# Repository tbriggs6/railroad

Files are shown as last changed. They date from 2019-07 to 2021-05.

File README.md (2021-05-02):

# railroad

Railroad Signal Controller

The Shippensburg Railroad Museum was restoring an antique railroad signalling lantern for the museum.  They asked me if I could help them activate the signals to follow the original standard patterns (e.g. go, stop, proceed with caution).  I agreed, and designed this board and the attached code for the embedded micrcontroller.

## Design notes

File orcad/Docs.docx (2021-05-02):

# Railroad Controller Board

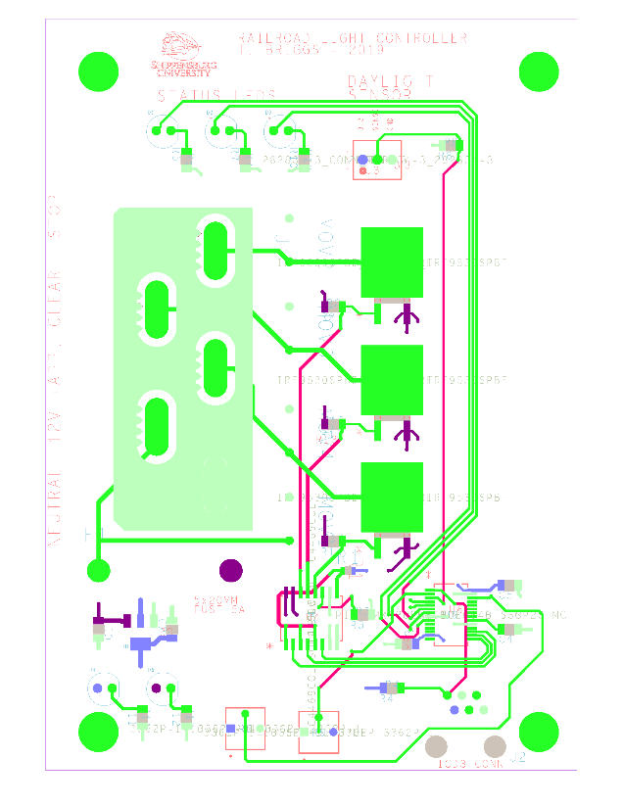
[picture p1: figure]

12V Fuse – 20mm x 5mm – 5A
Slow Blow (60 watt)

Daylight Sensor

Red (3V3+)

Yellow (Sensor)

Black (3V3-, Ground)

Adjust Light Speed

CCW – Faster

CW – Slower

Max CCW – Stop

Min CCW – 10 seconds

Adjust Daylight Cutoff

CCW – Darker

CW – Lighter

Full CCW – Always Off

Full CW – Always On

Status LEDs – Follow external lights

Stop Clear Approach

f

3mm Mounting Holes

Wires to the lights:

STOP

CLEAR

APPROACH

12VDC +

Ground / 12VDC -

# Theory of Operation

- Supports operation of three output channels corresponding to:
  - STOP,
  - CLEAR,
  - APPROACH.
- Only one output channel will be energized at a time.
- Output channel is connected to the positive rail of the external 12 VDC power supply
- Each output channel is expected to share a common ground with the negative rail of the 12 VDC supply.
- The speed of the pattern is controlled with a trimmer pot – allows speed from a fraction of second through approximately 30 seconds per channel, or 90 seconds for a complete cycle
- A daylight sensor is used to detect when there is sufficient sunlight for proper operation
- A trimmer pot can be used to adjust the level of sunlight that is sufficient
- Turning the daylight trimmer to one extreme will disable the output operation of the controller
- Turning the daylight trimmer to the other extreme will always enable the output operation of the controller (i.e. ignore the daylight sensor)
- The yellow power LED (bottom left corner of diagram) shows a sufficient 3.3V rail
- The red power LED (also bottom left corner) shows a sufficient 12V rail
- If the input fuse is blown then neither of the power LEDs will be lit
- The three status LEDs light-up with the corresponding output channel:
  - GREEN – Approach
  - YELLOW – Clear
  - RED - Stop

# Installation Notes

- The large 5-posn screw-down block holds the “high” voltage (12VDC connection)
  - Connect approximately 12 – 17 VDC to the indicated terminals
  - Connect the high-side of the signal LEDs to the output channels
- The small 3-posn screw-down block holds the “low” voltage daylight sensor
- The mounting holes are 3in and 4.5in (see template on page 1) and accommodate #4 - #8 machine screws.
- Negative rail should be connected to chassis ground or (preferably) earth ground to protect battery and other components from lightening, ground bounce, and attenuation due to length of buried wire

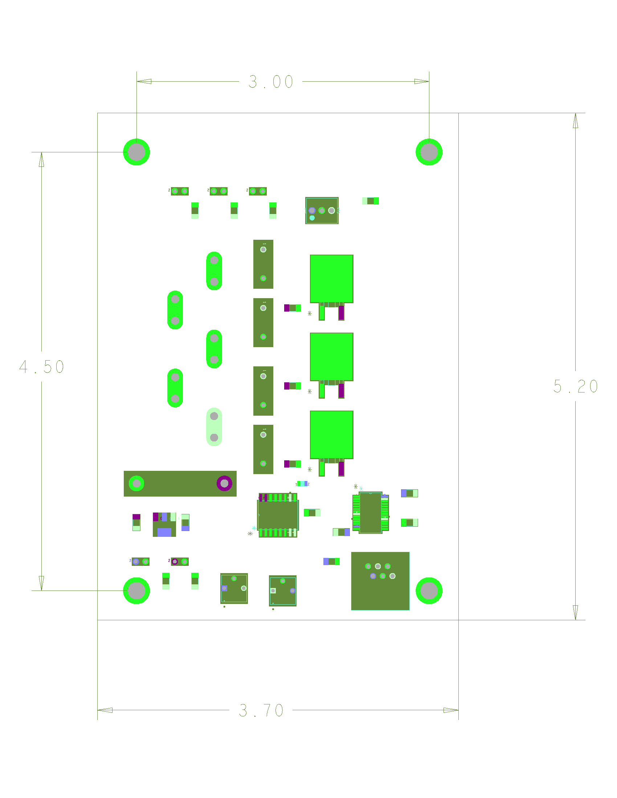
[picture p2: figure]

Figure 1 - Installation Template (not to scale)

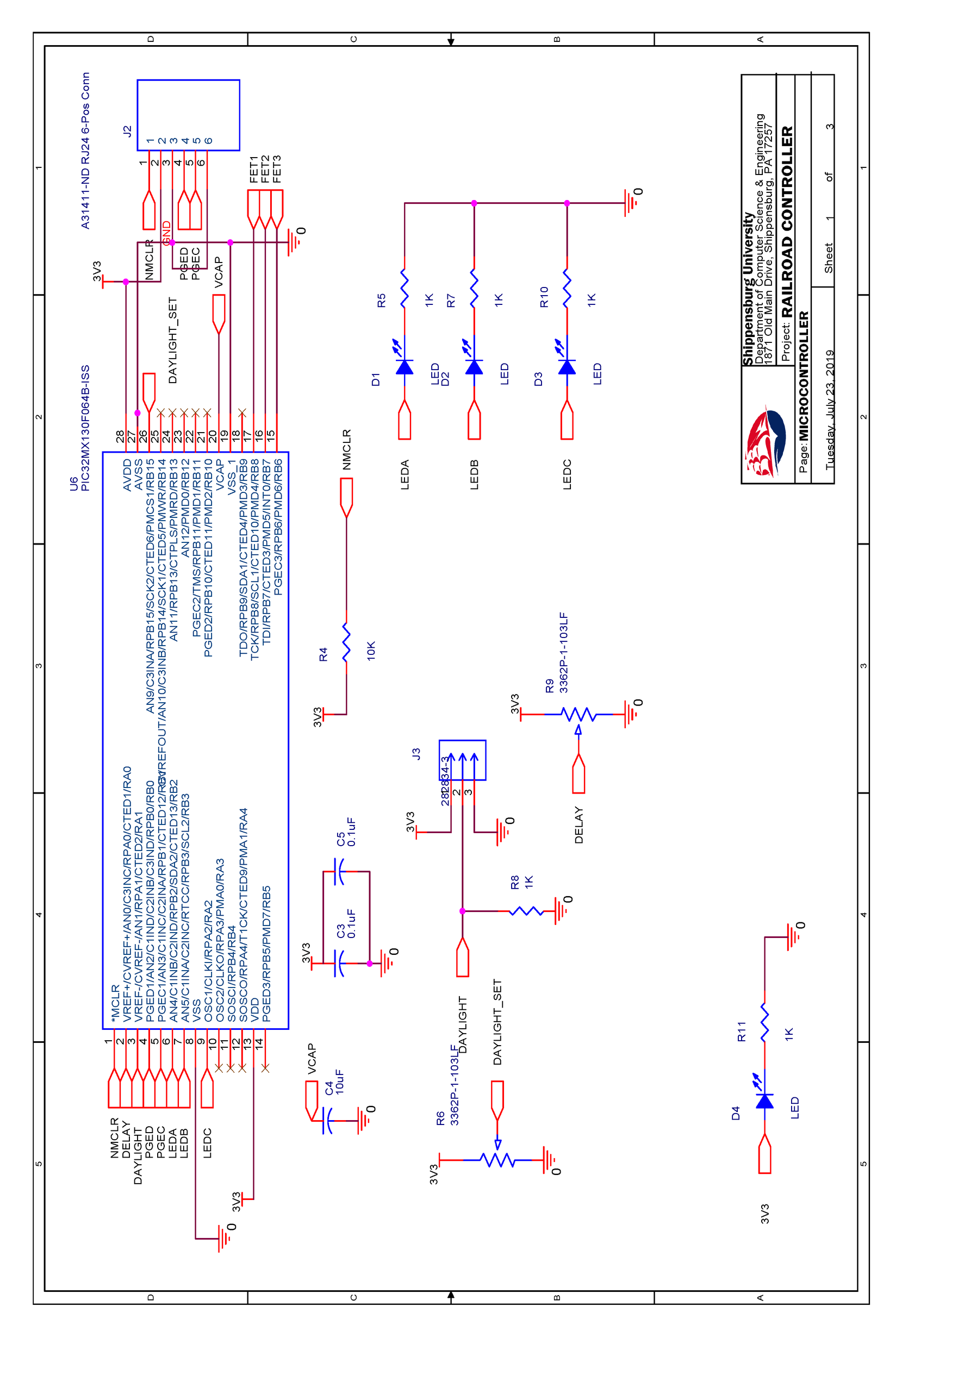
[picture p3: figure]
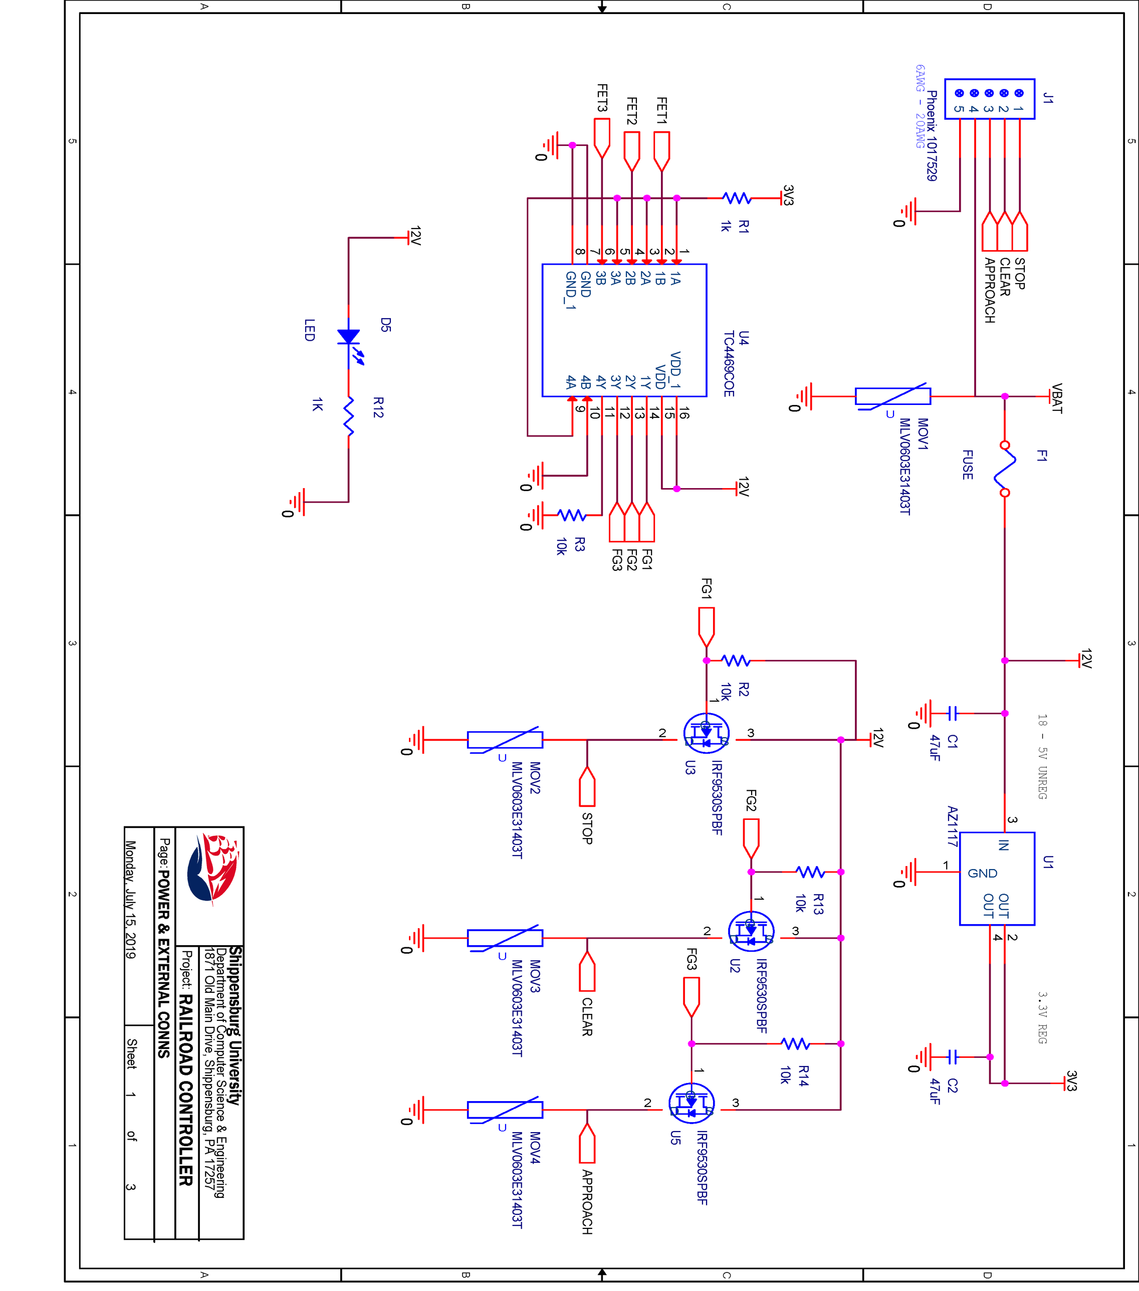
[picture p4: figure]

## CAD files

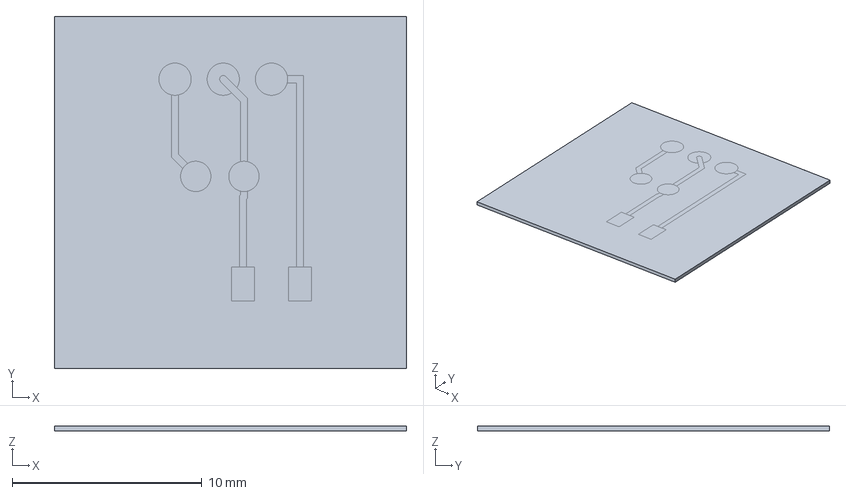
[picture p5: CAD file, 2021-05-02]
orcad/allegro/sensor.stp
18.5 x 18.5 x 0.295 mm
BOARD_OUTLINE
CIRCLE_66931 x 3
RECT_4724X70871 x 2
CIRCLE_62991 x 2
TRACES_TOP
SHAPES_TOP
CIRCLE_66932 x 3
CIRCLE_62992 x 2
TRACES_BOTTOM
SHAPES_BOTTOM

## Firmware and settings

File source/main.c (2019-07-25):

/**
  Generated Main Source File

  Company:
    Microchip Technology Inc.

  File Name:
    main.c

  Summary:
    This is the main file generated using PIC32MX MCUs

  Description:
    This header file provides implementations for driver APIs for all modules selected in the GUI.
    Generation Information :
        Product Revision  :  PIC32MX MCUs - pic32mx : v1.35
        Device            :  PIC32MX130F064B
        Driver Version    :  2.00
    The generated drivers are tested against the following:
        Compiler          :  XC32 1.42
        MPLAB             :  MPLAB X 3.55
*/

/*
    (c) 2016 Microchip Technology Inc. and its subsidiaries. You may use this
    software and any derivatives exclusively with Microchip products.

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
    IN NO EVENT WILL MICROCHIP BE LIABLE FOR ANY INDIRECT, SPECIAL, PUNITIVE,
    INCIDENTAL OR CONSEQUENTIAL LOSS, DAMAGE, COST OR EXPENSE OF ANY KIND
    WHATSOEVER RELATED TO THE SOFTWARE, HOWEVER CAUSED, EVEN IF MICROCHIP HAS
    BEEN ADVISED OF THE POSSIBILITY OR THE DAMAGES ARE FORESEEABLE. TO THE
    FULLEST EXTENT ALLOWED BY LAW, MICROCHIP'S TOTAL LIABILITY ON ALL CLAIMS IN
    ANY WAY RELATED TO THIS SOFTWARE WILL NOT EXCEED THE AMOUNT OF FEES, IF ANY,
    THAT YOU HAVE PAID DIRECTLY TO MICROCHIP FOR THIS SOFTWARE.

    MICROCHIP PROVIDES THIS SOFTWARE CONDITIONALLY UPON YOUR ACCEPTANCE OF THESE
    TERMS.
*/

#include "mcc_generated_files/mcc.h"

typedef enum {
    LED1, LED2, LED3
} led_state_t;

typedef enum {
    OFF, NORMAL, ON
} run_mode_t;

typedef struct {
    run_mode_t run_mode;
    uint32_t run_delay;
    uint32_t current_delay;
    led_state_t run_state;
    uint32_t daylight_count;
} global_state_t;

volatile global_state_t state;

typedef struct {
    uint32_t xmin;
    uint32_t ymin;
} lut_t;

typedef enum {
    DELAY, DAYLIGHT, DAYLIGHT_SET
} adc_channel_t;

#define SETPOINT_DEADZONE (50)
#define SETPOINT_OFF (0 + SETPOINT_DEADZONE)
#define SETPOINT_ON (1024 - SETPOINT_DEADZONE)
#define DAYLIGHT_MAX_COUNT 1000

typedef struct {
    uint32_t min;
    uint32_t max;
} range_t;

uint32_t compute_ratio(range_t x_range, range_t y_range, uint32_t x)
{
    // the fixed-point scale factors
    const uint32_t scale_delta = 1 << 7;
    const uint32_t scale_x = 1 << 14;
    
    // compute deltas
    uint32_t x_delta = x_range.max - x_range.min;
    uint32_t y_delta = y_range.max - y_range.min;
    
    // compute x's place in the range
    uint32_t x_in_range = x - x_range.min;
    
    // convert to fixed point
    uint32_t scaled_x_delta = x_delta * scale_delta;
    uint32_t scaled_x = x_in_range * scale_x;
    
    // compute the ratio (in fixed point)
    uint32_t ratio = scaled_x / scaled_x_delta;
    
    // compute the ratio
    uint32_t scaled_y = ratio * y_delta;
    
    // convert back from fixed point
    uint32_t value = scaled_y / (scale_x / scale_delta);
    
    // slide the scaled y back to its place in the range
    value = value + y_range.min;
    
    return value;
}


uint32_t compute_delay(uint32_t adc_value)
{
    static const lut_t lookup[5] = {
        { .xmin = SETPOINT_OFF, .ymin = 20 },
        { .xmin = 500, .ymin = 200 },
        { .xmin = 900, .ymin = 1500 },
        { .xmin = SETPOINT_ON, .ymin = 6000 },
        { .xmin = UINT32_MAX, .ymin = 50000 }
    };
    
    // gracefully handle errors in other parts of the code
    if (adc_value <= SETPOINT_OFF) return lookup[0].ymin;
    if (adc_value >= SETPOINT_ON) return lookup[4].ymin; 
    
    // find the entry in the table that adc_value comes *between*
    int i=0;
    while( (adc_value > lookup[i].xmin) && (adc_value > lookup[i+1].xmin)) {
        i++;
    }
    
    range_t adc_range = { .min = lookup[i].xmin, .max = lookup[i+1].xmin };
    range_t lut_range = { .min = lookup[i].ymin, .max = lookup[i+1].ymin };
    
    uint32_t ratio = compute_ratio(adc_range, lut_range, adc_value);

    if (ratio < lookup[0].ymin) ratio = lookup[0].ymin;
    if (ratio > lookup[4].ymin) return lookup[4].ymin; 
    return ratio;
}


void handle_adc( )
{
    uint32_t samps[ADC1_MAX_CHANNEL_COUNT];
  
    ADC1_ConversionResultBufferGet((uint32_t *)&samps, ADC1_MAX_CHANNEL_COUNT);

    if (samps[DAYLIGHT_SET] < SETPOINT_OFF) 
        state.run_mode = OFF;
    else if (samps[DAYLIGHT_SET] > SETPOINT_ON)
        state.run_mode = ON;
    else {
        
        if (samps[DAYLIGHT] < samps[DAYLIGHT_SET]) {
            state.daylight_count++;
            
            if (state.daylight_count > DAYLIGHT_MAX_COUNT) {
                // saturate the daylight counter and then turn off
                state.daylight_count = DAYLIGHT_MAX_COUNT; 
                state.run_mode = OFF;
            }
            else
                state.run_mode = NORMAL;
        }
        else {
            if (state.daylight_count > 0)
                state.daylight_count--;
            
            if (state.daylight_count == 0)
                state.run_mode = NORMAL;
            else
                state.run_mode = OFF;
            
        }
    }
    
    if ((state.run_mode == NORMAL) || (state.run_mode == ON)){
        uint32_t value_delay = samps[DELAY];
        state.run_delay = compute_delay(value_delay);
    }
    
 
    
}

void set_leds(int ledA, int ledB, int ledC)
{
    if (ledA == 1) {
        LATBbits.LATB2 = 1;
        LATBbits.LATB8 = 1;
    }
    else {
        LATBbits.LATB2 = 0;
        LATBbits.LATB8 = 0;
    }
    
    if (ledB == 1) {
        LATBbits.LATB3 = 1;
        LATBbits.LATB7 = 1;
    }
    else {
        LATBbits.LATB3 = 0;
        LATBbits.LATB7 = 0;
    }
    
    if (ledC == 1) {
        LATAbits.LATA2 = 1;
        LATBbits.LATB6 = 1;
    }
    else {
        LATAbits.LATA2 = 0;
        LATBbits.LATB6 = 0;
    }
}


void handle_timer( )
{
    WDTCONSET = 0x01; // Service the WDT
    
    if (state.run_mode == OFF) {
        state.current_delay = 0;
        state.run_state = LED1;
    }
    
    state.current_delay++;
    if (state.current_delay > state.run_delay) {
        state.current_delay = 0;
        
        switch(state.run_state) {
            case LED1: state.run_state = LED2;
            break;
            
            case LED2: state.run_state = LED3;
            break;
            
            case LED3: state.run_state = LED1;
            break;
            
            default: state.run_state = LED1;
            break;
            
        } // end switch
    } // end if
    
    if (state.run_mode == OFF){
        set_leds(0,0,0);
    }
    else {
        switch(state.run_state) {
            case LED1: set_leds(1,0,0);
            break;
            
            case LED2: set_leds(0,1,0);
            break;
            
            case LED3: set_leds(0,0,1);
            break;
            
            default: set_leds(0,0,0);
            break;
        } // end switch
    } // end else

       ADC1_Sample();
}  // end handle_timer

/*
                         Main application
 */
int main(void)
{
//    // initialize the device
    SYSTEM_Initialize();
    
    
    while (1)
    {
        // Add your application code
    }

    return -1;
}
/**
 End of File
*/

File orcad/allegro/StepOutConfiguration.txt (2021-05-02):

EXPORT_UNIT = Millimeter
EXPORT_PROTOCOL = 214
BARE_BOARD_ONLY = YES
HILIGHTED_PKG = NO
ALT_STEP = NO
IGNORE_STEPDEF = NO
MAPPED_PACKAGE = NO
UNMAPPED_PACKAGE = NO
EXTERNAL_COPPER = YES
INNER_COPPER = NO
MECH_PART = NO
MECH_DRILL = YES
PIN_DRILL = YES
VIA_DRILL = YES
ZIP_FILE = NO

SOURCE_ID = allegro_17.2S055

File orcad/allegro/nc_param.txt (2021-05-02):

INTEGER-PLACES         2
DECIMAL-PLACES         5
X-OFFSET               0.000000
Y-OFFSET               0.000000
FEEDRATE               1
COORDINATES            ABSOLUTE
OUTPUT-UNITS           ENGLISH
TOOL-ORDER             INCREASING
REPEAT-CODES           YES
SUPPRESS-LEAD-ZEROES   YES
SUPPRESS-TRAIL-ZEROES  NO
SUPPRESS-EQUAL         NO
TOOL-SELECT            YES
OPTIMIZE_DRILLING      NO
ENHANCED_EXCELLON      YES
HEADER                 none
LEADER                 12
CODE                   ASCII
SEPARATE               YES
SEPARATE-ROUTING       NO
DRILLING               LAYER-PAIR
BACKDRILL              NO
CAVITY                 NO
COUNTER                NO
TOLERANCE_DRILL        NO
TOLERANCE_TRAVEL       NO
TOOL_SIZE              NO
ROTATION               NO
NON_STANDARD           NO
TOTAL_DRILL            NO
SEPARATE_SLOT          NO
SUPPRESS_TOLERANCE     NO
SUPPRESS_TOOLSIZE      NO
SUPPRESS_ROTATION      NO

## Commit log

2019-07-25 Initial checkin of railroad project.
2021-05-02 Merged source and OrCAD
    [DESIGN1.DSN, RAILLROAD.brd, Raillroad.dsn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]
